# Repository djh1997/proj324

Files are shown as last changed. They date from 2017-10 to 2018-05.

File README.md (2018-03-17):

# **Final Year Project**

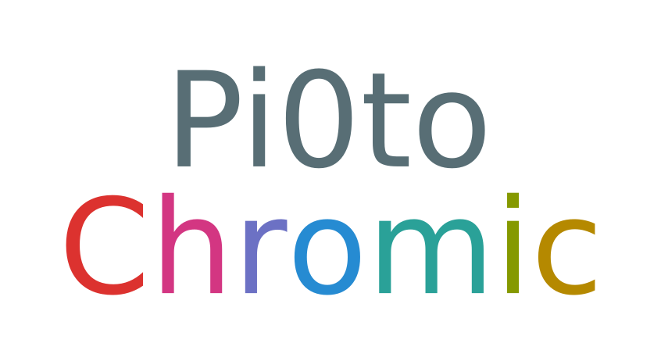
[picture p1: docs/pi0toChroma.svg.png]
pi0toChroma logo


# Stage Criteria

This is the criteria I would like to meet, to feel as though I have created a successful project.

| Stage | Name | Description |
| ----- | --- | --- |
| 1 | Smart shades | Make a set of smart sun classes |
| 2 | Auto smart shades | Add LDR to control the opacity |
| 3 | Auto smart point shades | Add camera to make dark point over bright points |
| 4 | Controllable smart shades | Add options to swap between modes |
| 5 | Driving/safety improvements | Auto react headlights etc. |

## Inspiration

[indie-go-go](https://www.indiegogo.com/projects/ctrl-one-the-smartest-lcd-tint-changing-glasses-smart#/)

[ctrl-eyewear](http://www.ctrl-eyewear.com/)

[pc case](https://www.youtube.com/watch?v=E5d7ynJXiZc)

## Plan

The product's above, along with Paul's lectures last year inspired my idea.

The plan is to use two LCD's with the backlight removed, to create dimmable panels in front of the users eyes. Then eventually I will add a camera to make point control which will block bright spots such as projectors and the sun, and dim them to reduce squinting.

# Final mock-up

final mock-up design image

So, once I have removed the backlight from the LCD's I can mount them in a frame. I can then begin to control the contrast/pixel density to make them dim. I will then add a LDR to automate the brightness selection, this will remove the manual adjust however I will leave the buttons to set the levels. Next I will add a camera to the system so that the system can also detect bright points hence make a matching point darker on the lens. I will then use the buttons to make it so that you can swap between the modes. The final additional feature I would like to add is some intelligence on the camera side to ignore certain circumstances such as car tail/headlights

# Report

I got the LCD hooked up and displayed some random spots of different opacity on the screen

[random point video](/docs/log/IMG_1188.TRIM.MOV)

I tried to install opencv to do the image processing built the install failed and after I spoke to my supervisor he confirmed my suspicion that opencv was too over powered for my project

so I did some more research around low power blob detection in python and found Skimage which has a function for Determinant of Hessian(doh) blob detection which should be quick enough the only issue I then had was getting the image from the camera into the right format since the doh blob need a numpy array as luck would have it skimage has a built in converter

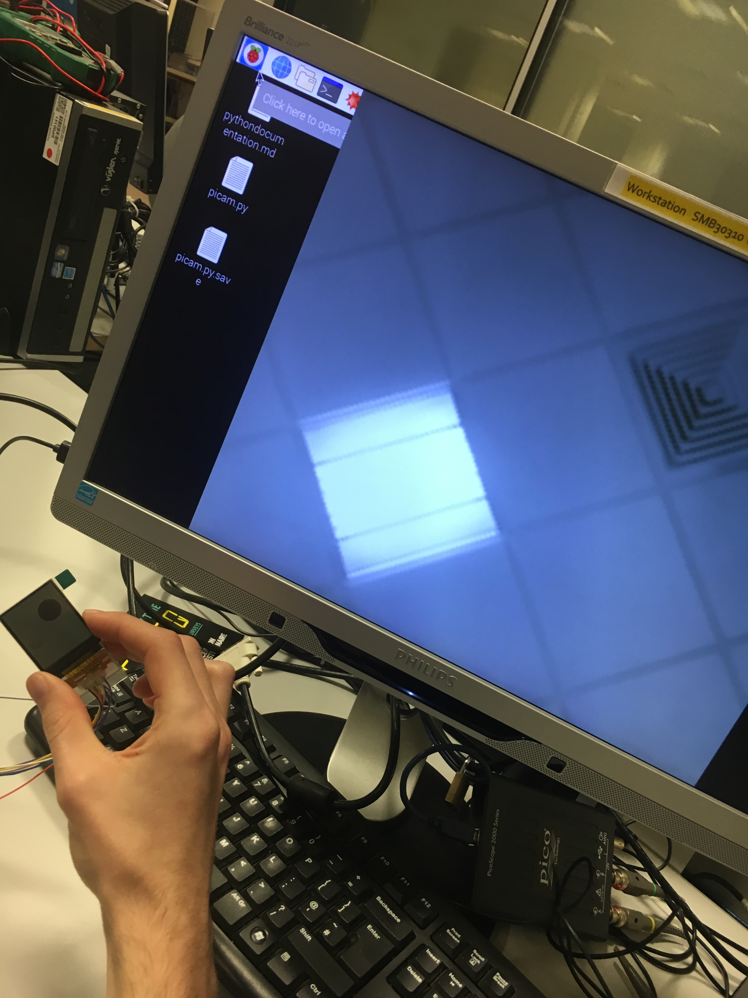
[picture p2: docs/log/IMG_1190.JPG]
final mock-up design image
I then connected the camera and started blob detection and got that working 

then I started to convert the shades.py (the file that controls the lcd and camera) and telegrambot.py (the script that enables remote control via a chat client bot) this involved more work than I had initially expected since passing variable around wasn't as easy as I had hoped

I decided to use telegram to add remote control so that you could adjust the colour of the tint [remote control](https://t.me/smartsheadsfypbot)

| command | param | Description |
| --- | --- | --- |
| help | na | show the help menu |
| pickcolour  | pick from list of tints | preset tints/colours |
| pickmode | pick manual,tint,points or full auto | change current mode |
| tellmeajoke | na | tells a joke |
| tint | percentage | sets the tint of the lenses |
| up | na | see if the bot is up |
| temp | na | see the CPU temperature |
| start | na | starts shades |
| stop | na | stop shades |
| exit | na | exit shades |
| reboot | na | reboot shades |
| halt | na | shutdown shades |
| uprecords | na | see up time |
| debug | na | toggles debug |
| colourset | fore/back@0/255,0/255,0/255 | sets the colour of the lenses |
| allowAllIds | na | toggles if user id is needed  |

After I had all of the system working I bought a 5 button capacitive touch sensor and started adding that into the code so that I would be able to control the glasses with out having to have it connected to the internet

| button | pressed | held |
| --- | --- | --- |
| 1 | scroll tints | reset tint to clear |
| 2 | scroll modes | reset to manual |
| 3 | debug | turn off |
| 4 | stop | start |
| 5 | na | exit |

# capacitive touch control

[mode change](/docs/log/capmode.MOV)
[tint change](/docs/log/tint.MOV)
[debug toggle](/docs/log/debug.MOV)

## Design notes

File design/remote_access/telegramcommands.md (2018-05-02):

help - show the help menu
pickcolour - pick from list of tints
pickmode- manual,tint,points or full auto
tint - percentage
image - shows you the current image
up - see if the bot is up
temp - see the CPU temperature
start - starts shades
stop - stop shades
exit - exit shades
reboot - reboot shades
halt - shutdown shades
uprecords - see up time
debug - toggle debug
buttons - toggle buttons
colourset - fore/back@0/255,0/255,0/255
allowallids - toggles if admin id is required

| command | param | Description |
| --- | --- | --- |
| help | na | show the help menu |
| pickcolour  | pick from list of tints | preset tints/colours |
| pickmode | pick manual,tint,points or full auto | change current mode |
| tint | percentage | sets the tint of the lenses |
| image | na | shows you the current image |
| up | na | see if the bot is up |
| temp | na | see the CPU temperature |
| start | na | starts shades |
| stop | na | stop shades |
| exit | na | exit shades |
| reboot | na | reboot shades |
| halt | na | shutdown shades |
| uprecords | na | see up time |
| debug | na | toggles debug |
| colourset | fore/back@0/255,0/255,0/255 | sets the colour of the lenses |
| allowAllids | na | toggles if admin id is needed |

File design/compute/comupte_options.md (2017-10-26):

<http://www.st.com/content/st_com/en/products/microcontrollers/stm32-32-bit-arm-cortex-mcus/stm32-high-performance-mcus/stm32f4-series/stm32f429-439/stm32f429zi.html>

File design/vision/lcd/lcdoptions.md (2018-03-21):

<http://uk.rs-online.com/web/p/oled-displays/0554314/>

<http://uk.farnell.com/midas/mct0144c6w128128pml/display-tft-lcd-1-44-transmissive/dp/2606862>

# lcd

[pickedlcd](https://www.adafruit.com/product/618)

## pinout

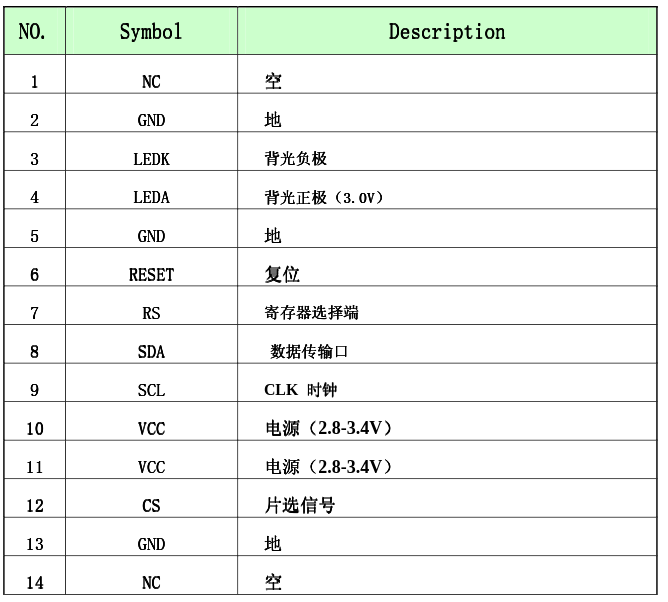
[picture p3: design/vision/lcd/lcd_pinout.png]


| lcd pin number | name  | used | colour | pi pin |
| --- | ----- | ---- | --- | --- |
| 1 | NC | no | na | |
| 2 | gnd | ? | purple | 20 |
| 3 | ledk  | no | na | |
| 4 | leda  | no | na | |
| 5 | gnd | ? | pink | 20 |
| 6 | reset | yes  | blue | 22 |
| 7 | rs/dc | yes  | grey | 18 |
| 8 | sda | yes  | yellow | 19 |
| 9 | scl | yes  | green  | 23 |
| 10 | vcc | yes  | orange | 17 |
| 11 | vcc | yes  | na | |
| 12 | cs | yes  | white  | 24 |
| 13 | gnd | ? | black  | 20 |
| 14 | NC | no | na | |

# lcd maths

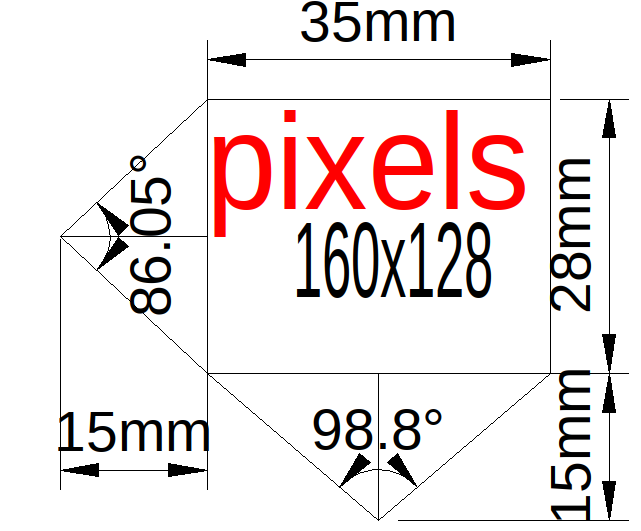
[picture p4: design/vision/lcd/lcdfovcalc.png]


$$ { \frac {128} {86.05}} = 1.48 \text{ vertical degrees per pixel}$$

$$ { \frac {160} {98.8}} = 1.62 \text{ vertical degrees per pixel}$$

# pi points

| function | colour | pi pins chip side | pi pin | colour  | function |
| --- | --- | --- | --- | --- | --- |
| vcc | orange | 17 | 18 | grey | rs |
| sda | yellow | 19 | 20 | black/p | gnd |
| | nc | 21 | 22 | blue | reset |
| scl | green  | 23 | 24 | white | cs |

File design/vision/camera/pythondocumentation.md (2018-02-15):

[docs](https://picamera.readthedocs.io/en/release-1.13/index.html)

- 5MP sensor, 2592x1944 pixels (same as version 1 official Pi camera)
- 1080p video at 30 FPS (or 60 FPS at 720p, 90 FPS at 480p)
- f2.9 lens, 3.60 mm focal length
- 53.50 degrees horizontal, 41.41 degrees vertical field of view (standard and no IR filter versions)
- Approx. dimensions of circuit and camera: 60 x 11.4 x 5.1mm

```bash
sudo apt-get update
sudo apt-get install python3-picamera
```

```python
import picamera
from time import sleep

camera = picamera.PiCamera()

camera.capture('image1.jpg')
sleep(5)
camera.capture('image2.jpg')
```

opencv failed to install and Phil said i would be better off using a simpler program to reduce compute time so am looking at numpy and [skimage](https://github.com/scikit-image/scikit-image)

[b&w image](https://picamera.readthedocs.io/en/release-1.13/api_camera.html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)

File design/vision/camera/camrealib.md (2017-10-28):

<https://os.mbed.com/users/edodm85/notebook/ov7670-camera-module/>

<https://os.mbed.com/users/ms523/notebook/ov7670-camera/>

<http://www.instructables.com/id/OV7670-Without-FIFO-Very-Simple-Framecapture-With-/>

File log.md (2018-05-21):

# Tasks

-   [x] get camera working
-   [x] get pi connected over WiFi
-   [x] get LCD connected
-   [x] get raw data from camera for processing
-   [x] get raw brightness from LDR or camera
-   [x] adjust opacity of LCD
-   [x] add image inversion
-   [x] add options to swap between modes
-   [x] laser cut glasses frame

# Extras

-   [x] add some form of app to control settings
-   [x] add options for dimming colour e.g. turn tint red instead of grey tint

# 16/11/2017

connect raspberry pi zero to home WiFi and successfully take photos

# 17/11/2017

successfully connect pi0w to eduroam and take photos

# 18/11/2017

start designing the frame

# 19/11/2017

start work with LCD

-   find c++ library from adafruit [ST7735-c+++](https://github.com/adafruit/Adafruit-ST7735-Library)
-   find python library [ST7735-micro](https://github.com/hosaka/micropython-st7735), [ST7735-af c++ forked to py](https://github.com/cskau/Python_ST7735)

looking thought the code the ST7735-micro seems cleaner and looks like I will be able to modify it easier since it is broken into more small functions although the other python has image support so I will try both and access

# 02/02/2018

start working on project again after exams/coursework and Christmas break but WiFi has stopped working possibly because of certification update but even reslashing the board and rerunning the cat installer didn't work will try to connect when I get home to check the WiFi chip is still working talked to Jake and said he should be able to put it on Plymouth humanoids

# 05/02/2018

work on time management and issue tracking

# 06/02/2018

today I finally got the pi0w connected to the uni WiFi and also got the vnc working so that I could work on the pi in uni without brining in a separate screen for the pi once I had done that I started work on the field of view calculations and realised that with out a fisheye camera adapter the lcd has a bigger fov so only the centre will be usable for point adjustment I also calculated the pixels per angle and realise that the only issue with using a fish eye adapter would cause distortion

then followed this [guide](https://www.pyimagesearch.com/2015/12/14/installing-opencv-on-your-raspberry-pi-zero/) to install open cv reach

```bash
pip install numpy
```

before running out of time before space x falcon heavy launch

# 07/02/2018

spacex falcon heavy launch was a success

-   switch to opencv 3.4.0 and finish up install
-   add all dependences to repo

# 08/02/2018

install locked at 84%

# 09/02/2018

get lcd and pi0w header soldered and get pin mappings for each

# 13/02/2018

looking through the code for the lcd drivers again from (19/11/2017) I think the forked adafruit might be better

found skimage and think it will work well with camera

also make new simpler frame prototype ready for laser cutting

# 14/2/2018

had meeting with Phil and he seems happy with progress and direction I'm taking so all good there

# 15/02/2018

got lcd working and even got the lcd to output circles based on x,y,radius,opacity

got blob detection working 'live'

# 16/02/2018

got both lcds working and fine tune timings to work out where the issues are and fine tune the blob detection

# 17/02/2018

tidied files up and got telegram control integrated into shades with control over weather point detection is on or off and the colour / tint level

# 20/02/2018

finalized remote control(4 modes, more colours and toggle-able debug ) and begin optimizing code to try to improve fps f

# 27/02/2018

investigate [capacitve](https://www.rapidonline.com/adafruit-1362-standalone-5-pad-capacitive-touch-sensor-breakout-73-5337) control of system and mount the lenses into the frame and add price list

# 03/03/2018

begin investigating conversion to c/c++ command

```bash
raspistill -o cam.jpg -cfx 128:128 -ifx negative -w 160 -h 128 -rot 270 --thumb none -l
```

```bash
raspistill -t 1000 -tl 0 -o - > img.jpg -cfx 128:128 -ifx negative -w 160 -h 128 -rot 270 --thumb none
```

find [raspicam](http://www.uco.es/investiga/grupos/ava/node/40) cpp api for the camera possible [st7735R](https://github.com/vinodstanur/raspberry-pi-frame-buffer-mapping-to-160x128-ST7735R-LCD) library although might be screen output

[blob](https://github.com/keenerd/quickblob)

achieve 30 fps image stream although the new blob detection might be able to deal with video stream

# 08/03/2018

receive parts and measure current draw at .2/.3 A and start coding for capacitive buttons

# 12/03/2018

finish initial coding for capacitive buttons

# 13/03/2018

fully implement hold for extra functionality

# 14/03/2018

tidy button code and start thinking about mounting

# 16/03/2018

record progress and prep for progress demonstration

# 9/04/2018

implement addwifi so I can add wifi AP's easier using Telegram

# 12/04/2018

tidy debugging prints and improve access error text

# 17/04/2018

redesign the fame for capacitive board and tidy deinitialization of camera

# 20/04/2018

add print to debug toggle, add commenting, add link to access error reply, start making install script to install dependencies

# 22/04/2018

add time to boot and reboot reply to calculate reboot time

# 23/04/2018

tidy code and make pep257 compliant, only update LCD on value change in manual mode

# 24/04/2018

work on report and get new arms cut,fix error #29 ,and add exit functionality so reopen program

# 26/04/2018

do paper work and move telegram API keys to separate file

# 30/04/2018

tidy code by moving jokes, making buttons more dynamic and work on report

# 01/05/2018

work on report, poster and add try except to telegrambot

# 02/05/2018

get toggle-able buttons working and add more diagrams to the poster

# 08/05/2018

add vision explanations and get mum to read thought report

# 09/05/2018

improve wiring and work on poster and report

# 10/05/2018

add button diagram to poster and add references to Appendix, gantt and budget to report also I improved the inspiration section

# 11/05/2018

finalize poster add compute, LCD and camera choice

# 12/05/2018

add negative image mode and work on report

# 13/05/2018

embed images add existing market and relevant references

# 14/05/2018

add toc and glossary

# 16/05/2018

get report checked at writing cafe

# 18/05/2018

add more references and add abstract, acknowledgements

# 19/05/2018

improve general formatting ,add licence

# 20/05/2018

work on report add flowchart and correct gantt

# 21/05/2018

add telegram inline keyboard screen shot and open day photo

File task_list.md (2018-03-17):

-   [x] find LCD's
-   [x] remove backlight
-   [x] get pi connected to WiFi
-   [x] get camera working
-   [x] export DISPLAY=:0.0
-   [x] telegram intergration [inline keyboard](https://github.com/python-telegram-bot/python-telegram-bot/blob/master/examples/inlinekeyboard.py)
-   [ ] frame
-   [ ] task

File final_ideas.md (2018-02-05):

# Stage Criteria

This is the criteria I would like to meet, to feel as though I have created a successful project.

| Stage | Name | Description |
| ----- | --- | --- |
| 1 | Smart shades | Make a set of smart sun classes |
| 2 | Auto smart shades | Add LDR to control the opacity |
| 3 | Auto smart point shades | Add camera to make dark point over bright points |
| 4 | Controllable smart shades | Add options to swap between modes |
| 5 | Driving/safety improvements | Auto react headlights etc. |

## Inspiration

[indie-go-go](https://www.indiegogo.com/projects/ctrl-one-the-smartest-lcd-tint-changing-glasses-smart#/)

[ctrl-eyewear](http://www.ctrl-eyewear.com/)

[pc case](https://www.youtube.com/watch?v=E5d7ynJXiZc)

## Plan

The product's above, along with Paul's lectures last year inspired my idea.

The plan is to use two LCD's with the backlight removed, to create dimmable panels in front of the users eyes. Then eventually I will add a camera to make point control which will block bright spots such as projectors and the sun, and dim them to reduce squinting.

# Initial mock-up of design initial mock-up image

# Final mock-up final mock-up design image

So, once I have removed the backlight from the LCD's I can mount them in a frame. I can then begin to control the contrast/pixel density to make them dim. I will then add a LDR to automate the brightness selection, this will remove the manual adjust however I will leave the buttons to set the levels. Next I will add a camera to the system so that the system can also detect bright points hence make a matching point darker on the lens. I will then use the buttons to make it so that you can swap between the modes. The final additional feature I would like to add is some intelligence on the camera side to ignore certain circumstances such as car tail/headlights

# VHDL/FPGA(de o nano) vs. arm(stm32 vs. RPI)

I am currently undecided on the compute platform.

I'm leaning towards the arm side since the camera will likely be 30-60 fps and I believe that the arm will be quick enough. Also I think it will have better support for interfacing the camera and LCD also the STM boards have analogue io for the LDR and contrast for the LCD

After talking to my supervisor and lab tech they both recommended the raspberry pi as the platform. this recommendation is because of the price point of the zero w and the zero cam being so low and the large product support for the increased range of screens possible the only issue with this will be the fact the pi doesn't have analogue io so the dimming of the LCD will be harder but this should be easily worked around.

| component | quantity | price(£) | component type | chosen |
| --- | --- | --- | --- | --- |
| pi zero w | 1 | 9.60 | compute | yes |
| pi 3 | 1 | 35 | compute | no |
| stm32 | 1 | 18.11 | compute | no |
| de0nano | 1 | 67.16 to 84.46  | compute | no |
| MCT0144C6W128128PML | 2 | 7.57 | lens | no |
| DD-12864YO-3A | 2 | 16.12 | lens | no |
| AF 1.8" TFT ST7735R driver | 2 | 10 | lens | yes |
| pi zero camera | 1 | 15 | camera | yes |
| pi camera | 1 | 24 | camera | no |
| ov7670 | 1 | 5 to 10 | camera | no |
| ov7720 | 1 | .50 from ps eye | camera | no |
| DAC 0800 | 1 | 1.15. | DAC for LCD | yes |
| ZN439 | 1 | 2.50 | ADC for LDR | yes |

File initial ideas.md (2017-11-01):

# stage criteria

These are the criteria I would like to meet to feel as thought I have ached a successful project.

stage | name                        | description
----- | --------------------------- | ----------------------------------------------
1     | smart shades                | make a set of smart sun classes
2     | auto smart shades           | add LDR to control the opacity
3     | auto smart point shades     | add camera to make dark point over dark points
4     | controllable smart shades   | add options to swap between modes
5     | driving/safety improvements | auto react headlights ect.

## Inspiration

[indiegogo](https://www.indiegogo.com/projects/ctrl-one-the-smartest-lcd-tint-changing-glasses-smart#/)

[ctrl-eyewear](http://www.ctrl-eyewear.com/)

[pc case](https://www.youtube.com/watch?v=E5d7ynJXiZc)

## plan

this product along with Paul's lectures last year inspired the idea.

The plan is to use two LCD's with the backlight removed to create dimmable panels in front of the users eyes. Then eventually add a camera to make point control to block bright spots like projectors and the sun and dim them to reduce squinting.

# initial mock-up of design inital mock-up image

# hopeful final mock-up final mock-up design image

So once I have removed the backlight from the LCD's I can mount them in a frame I can then begin to control the contrast/pixel density to make them dim. I will then add a LDR to automate the brightness selection this will remove the manual adjust but I will Leave the buttons to set the levels. next I will add a camera to the system so that it can also detect bright points and make a matching point darker on the lens. I will then use the buttons to make it so you can swap between the modes. The final feature addition I would like to add is some intelligence on the camera side to ignore certain circumstances like car tail/headlights

# VHDL/FPGA(de o nano) vs. arm(stm32 vs. rpi)

I am currently undecided on the compute platform.

I'm leaning towards the arm side since the camera will likely be 30-120 fps and I believe that the arm will be quick enough. Also I think it will have better support for interfacing the camera and LCD also the STM boards have analogue i-o for the LDR and contrast for the LCD

After talking to my supervisor and lab tech they both recommended the raspberry pi as the platform. this recommendation is because of the price point of the zero w and the zero cam being so low and the large product support for the increased range of screens possible

component           | quantity | price(£)        | component type
------------------- | -------- | --------------- | --------------
pi zero             | 1        | 9.60            | compute
pi 3                | 1        | 35              | compute
stm32               | 1        | 18.11           | compute
de0nano             | 1        | 67.16 to 84.46  | compute
MCT0144C6W128128PML | 2        | 7.57            | lens
DD-12864YO-3A       | 2        | 16.12           | lens
pi zero camera      | 1        | 15              | camera
pi camera           | 1        | 24              | camera
ov7670              | 1        | 5 to 10         | camera
ov7720              | 1        | .50 from ps eye | camera

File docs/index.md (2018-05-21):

---
html:
  embed_local_images: true
---
# **Final Year Project**

pi0toChroma logo

By David Joseph Hawkins

Student no:10526354

School of Computing, Electronics and Engineering.

A report covering the theory, design, build and testing of a pair of dynamic sunglasses. Submitted to the University of Plymouth in partial fulfilment for the degree of BEng(Hons) Electrical and Electronic Engineering.

## Acknowledgements

A special thanks goes to my family, technical support staff, The Writing Cafe,  Philip Culverhouse and Nicholas Outram.

A thanks also goes to the makers of GitHub, GitGuardian, Telegram, Draw.io, Atom, GanttProject, Scikit-image, Etcher.io and Inkscape for their great services/software.

<!-- TOC depthFrom:1 depthTo:6 withLinks:1 updateOnSave:1 orderedList:0 -->

- [**Final Year Project**](#final-year-project)
	- [Acknowledgements](#acknowledgements)
	- [Glossary](#glossary)
- [Stage Criteria](#stage-criteria)
	- [Inspiration](#inspiration)
	- [Plan](#plan)
		- [Potential issues](#potential-issues)
		- [Timeline](#timeline)
- [Design Mock-up](#design-mock-up)
- [Report](#report)
	- [Compute](#compute)
		- [VHDL/FPGA(de0nano) vs. arm(STM32 vs. RPI)](#vhdlfpgade0nano-vs-armstm32-vs-rpi)
	- [Camera](#camera)
	- [LCD](#lcd)
		- [Theory](#theory)
		- [Wiring](#wiring)
		- [Testing](#testing)
	- [FoV](#fov)
		- [LCD](#lcd)
		- [Camera](#camera)
	- [Frame](#frame)
	- [Blob Detection](#blob-detection)
	- [Telegram](#telegram)
		- [Commands](#commands)
	- [Capacitive Touch Sensor](#capacitive-touch-sensor)
		- [Wiring](#wiring)
		- [Buttons](#buttons)
		- [Capacitive Touch Control](#capacitive-touch-control)
- [Conclusion](#conclusion)
	- [Criteria Met](#criteria-met)
	- [Budget](#budget)
	- [Time management](#time-management)
	- [Existing market](#existing-market)
	- [Technology readiness level](#technology-readiness-level)
- [Future Development](#future-development)
- [Appendix](#appendix)
	- [Coding languages](#coding-languages)
	- [Code](#code)
		- [telegrambot.py](#telegrambotpy)
		- [shades.py](#shadespy)

<!-- /TOC -->

## Glossary

| Abbreviation | Meaning |
| --- | --- |
| SPI | Serial peripheral interface |
| LDR | Light dependant resistor |
| LCD | Liquid crystal display |
| FPGA | Field programmable gate array |
| VHDL | Very high speed integrated circuit hardware description language |
| IO | Input output |
| GPIO | General purpose input output |
| FoV | Field of view |
| TRL | Technology readiness level |

# Stage Criteria

This is the criteria that the project aims to meet, to feel as though the project had succeeded.

| Stage | Name | Description |
| ----- | --- | --- |
| 1 | Smart shades | Make a set of smart sunglasses |
| 2 | Auto smart shades | Add LDR to control the opacity |
| 3 | Auto smart point shades | Add camera to make darks points over bright points |
| 4 | Controllable smart shades | Add options to swap between modes |
| 5 | Driving/safety improvements | Auto react to headlights etc. |

## Inspiration

The project was inspired by Linus tech tips video[^1] about the IBuyPower Snowblind case[^2]. It was then that the idea for reactive sunglasses using LCD was formed. While researching to see if this had already been done, ctrl-one glasses were discovered and have similarly been created[^3].

The ctrl-one product starts down the same path as this project would like to take but are binary whereas this project aims for different levels of tinting and active shading. To achieve this it will be required to use an LCD panel with pixels instead of a single panel. Also, one of the ctrl-one products main unique selling points is the sub 0.1 second light to dark time[^4]; which will ideally be surpassed. The other advantage this product will have over ctrl-one will be cost since, ctrl-one costs $299, while this product aims to be priced under £100[^5] (set by the budget limit).

## Plan

The products above, along with Paul Davey's lectures last year inspired the idea.

The plan is to use two LCD's with the backlight removed, to create dimmable panels in front of the users eyes. Then eventually a camera will be added to create multiple point controls which will block bright spots such as projectors and sunlight thus, dimming them to reduce squinting.

### Potential issues

-   IO speed, depending on the solutions used in the project, could end up being an issue with bottle necks affecting frame rate.
-   Frame rate for the active points would need to be fairly high to stop nauseating effects.
-   Camera distortion, a camera with little to no distortion would ideally be used since this would make image processing easier.
-   Field of view, having a similar FoV would be useful since a camera with smaller FoV would end up wasting the edge of the LCD.
-   Aspect ratio, mismatch of aspect ratios without the use of accelerometers for predictive tracking could cause issues.

### Timeline

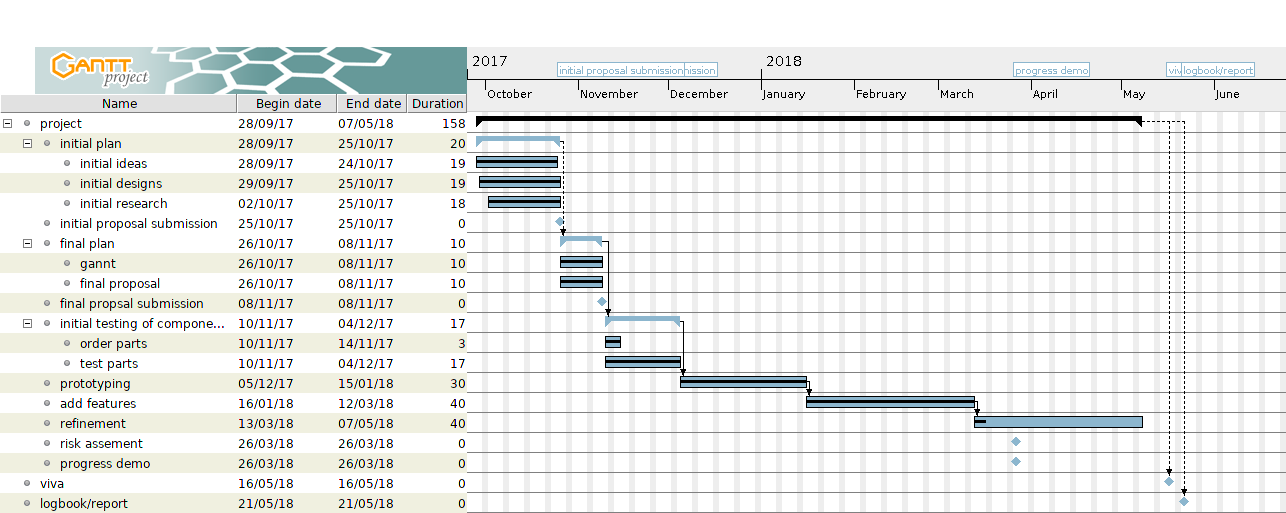
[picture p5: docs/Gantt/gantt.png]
gantt


A gantt chart was made using GanttProject[^6]

# Design Mock-up

final mock-up design image

So, once the backlight was removed from the LCD's they can mount them into the frame. Then the LCDs can begin to be controlled by adjusting the contrast/pixel density to make them dim using a button.

After which an LDR can be added to automate the brightness selection, the manual adjust however will be left in, at which point the button can still be used to switch between the different sensitivity levels.

Next a camera will be added to the system so that the system can detect bright points, hence make a matching point darker on the lens.

At which point the buttons can be used so that you can switch between different modes. The final additional feature that will be added is some intelligence on the camera side to ignore certain circumstances such as car tail/headlights.

# Report

## Compute

### VHDL/FPGA(de0nano) vs. arm(STM32 vs. RPI)

For the compute unit the main options available are arm or FPGA. Theoretically the FPGA will have higher parallel though put for the camera to LCD interface. Although arm will have image processing libraries which will expedite the prototyping process. The other main advantage with arm is the reduced cost.

| Component | Quantity | Price(£) | Component type | Chosen |
| --- | --- | --- | --- | --- |
| pi 0 w | 1 | 9.60 | compute | yes |
| pi 3 | 1 | 35 | compute | no |
| STM32 | 1 | 18.11 | compute | no |
| de0nano | 1 | 67.16 to 84.46 | compute | no |

I'm leaning towards the arm side since the camera will likely be 30-60 fps. I believe that an arm  chip will be quick enough. Also it will have better support for interfacing the camera and LCD; the STM boards have analogue IO for the LDR and contrast for the LCD.

After talking to supervisors and lab technicians they both recommended the raspberry pi as the platform. This recommendation is because of the price point of the zero w and the zero cam being so low as well as, the large product support for the increased range of screens possible. The only issue with this will be the fact the pi doesn't have analogue IO so the dimming of the LCD will be harder but this should be easily worked around.

The other advantage of the raspberry pi 0 is it has a file system and wifi so code can be remotely deployed once it is connected. This will make the development cycle much quicker.

## Camera

| Component | Quantity | Price(£) | Component type | Chosen |
| --- | --- | --- | --- | --- |
| pi 0 camera | 1 | 15 | camera | yes |
| pi camera | 1 | 24 | camera | no |
| ov7670 | 1 | 5 to 10 | camera | no |
| ov7720 | 1 | .50 from ps eye | camera | no |

The options for the camera were good but the pi 0 camera was picked, since it had the best compromise between cost and libraries[^7].

## LCD

LCD's will be used to reduce the amount of light reaching the users eyes. The way an LCD works is like a stain glasses window with a frosted glasses window and bright light behind. But with an LCD you can change the colour and brightness of the stain. This is the effect that will be used to dynamically adjust the amount of light reaching the users eyes.

| Component | Quantity | Price(£) | Component type | Chosen |
| --- | --- | --- | --- | --- |
| MCT0144C6W128128PML | 2 | 7.57 | lens | no |
| DD-12864YO-3A | 2 | 16.12 | lens | no |
| AF 1.8" TFT ST7735R driver | 2 | 10 | lens | yes |

The adafruit 1.8" TFT ST7735R is going to be the best option since it's the best size for the lenses. Also there are drivers[^8] available for the raspberry pi.

### Theory

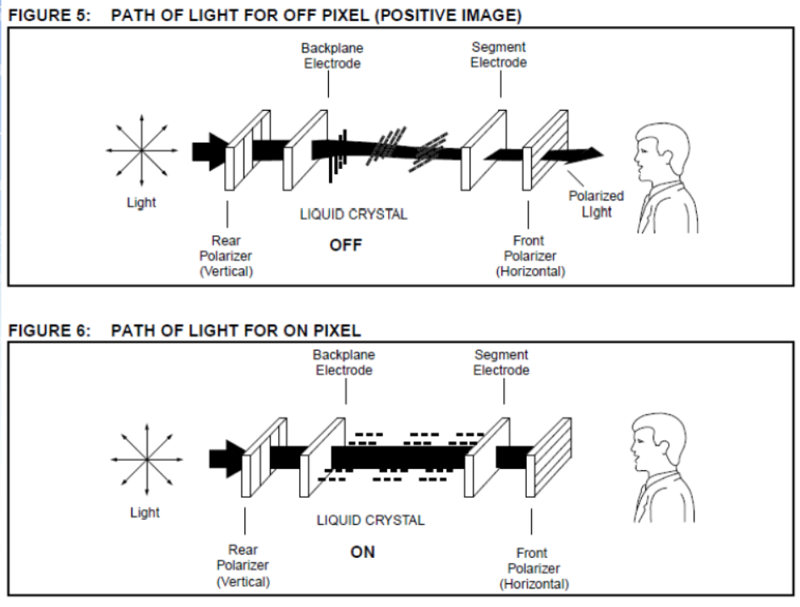
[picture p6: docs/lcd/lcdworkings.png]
LCD workings


In this diagram from Paul Davey's lecture[^9] on LCD's last year, you can see the inner workings of an individual pixel.

This works like so;

1.  Light enters the panel through the rear polariser. The light becomes vertically polarized.
2.  The polarized light then passes through the transparent backplane electrode.
3.  As the polarized light passes through the Liquid crystal fluid it gets twisted into the horizontal plane.
4.  The polarized light passes through the transparent pixel electrode.
5.  Because the light is polarized in the horizontal plane, it passes through the front horizontal polariser.

This is the effect that will be used to reduce the amount of light reaching the users eyes.

### Wiring

| Function | Colour | Pi pins chip side | Pi pin | Colour  | Function |
| --- | --- | --- | --- | --- | --- |
| vcc | Orange | 17 | 18 | Grey | rs |
| sda | Yellow | 19 | 20 | Black/P | gnd |
| N/A | nc | 21 | 22 | Blue | reset |
| scl | Green  | 23 | 24 | White | cs |

### Testing

I connected the LCD and displayed some random size and location spots of different opacity on the screen.

[random point video](https://git.djh1997.uk/log/IMG_1188.TRIM.MOV)

After this, the entire screen was set to one tint, then changed to a different tint. This meant you could see the update "wipe" across the screen.

This will cause issues since the SPI is already at the max speed.

It was also tried to consolidate/disconnect the grounds of the LCD but this caused issues so the wiring was returned to the original configuration.

## FoV



Field of view(FoV) is the area that you can see. It is normally measured in degrees. For simple mapping it is required that the FoV of the camera and LCD to be the same. Other issues include;

Aspect ratio


Distortion
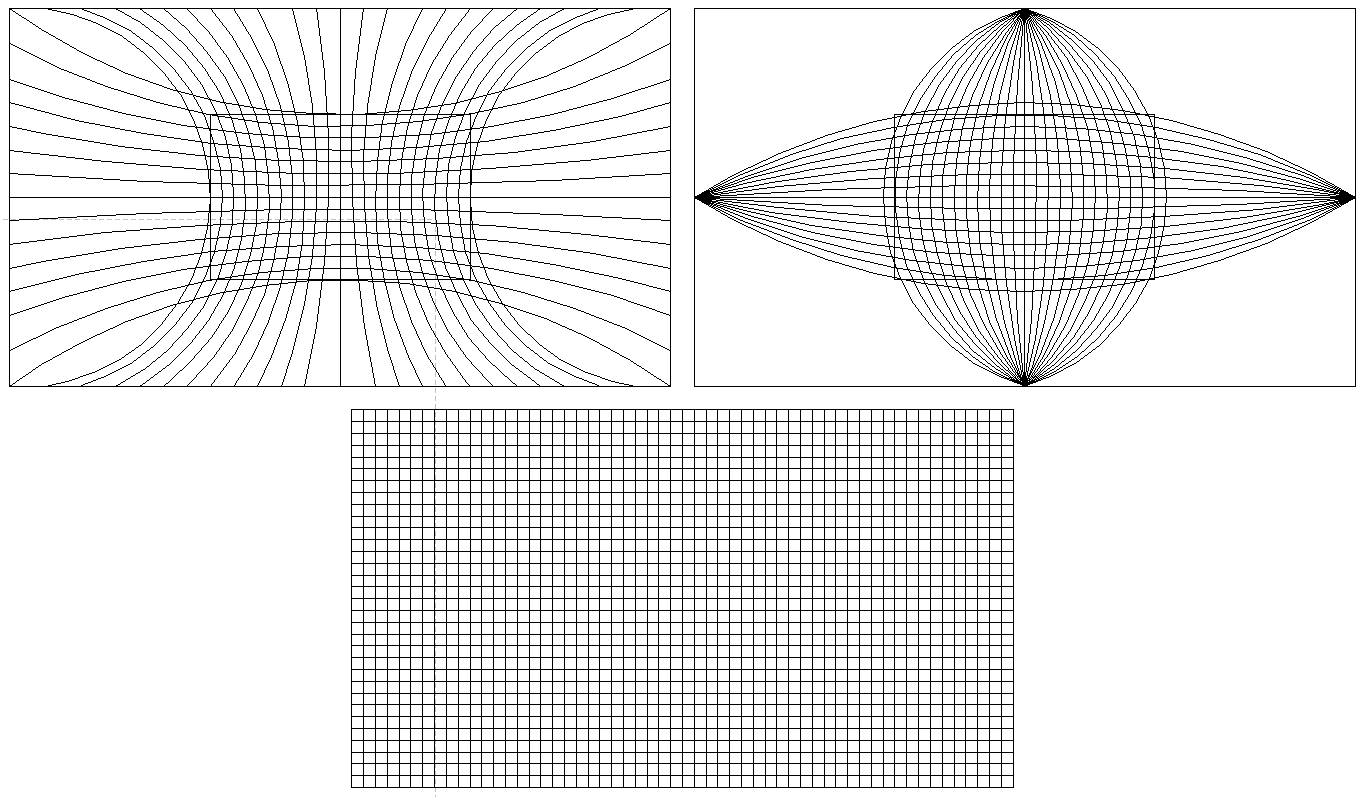
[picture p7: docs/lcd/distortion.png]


### LCD


160x128 pixels

98.8 degrees horizontal, 86.05 degrees vertical field of view

$$ { \frac {128} {86.05}} = 1.48 \text{ vertical pixels per degree}$$

$$ { \frac {160} {98.8}} = 1.62 \text{ horizontal pixels per degree}$$

### Camera

2592x1944 pixels

53.50 degrees horizontal, 41.41 degrees vertical field of view

$$ { \frac {1944} {41.41}} = 46.95 \text{ vertical pixels per degree}$$

$$ { \frac {160} {98.8}} = 48.45 \text{ vertical pixels per degree}$$

So, this will cause issues since the dot placed on the LCD will end up in the wrong place without scaling.

## Frame

The frame was cut by a laser cutter since this would be more cost and time effective. Also glasses frames tend to be fairly 2-dimensional. In the following image you can see the design iterations.

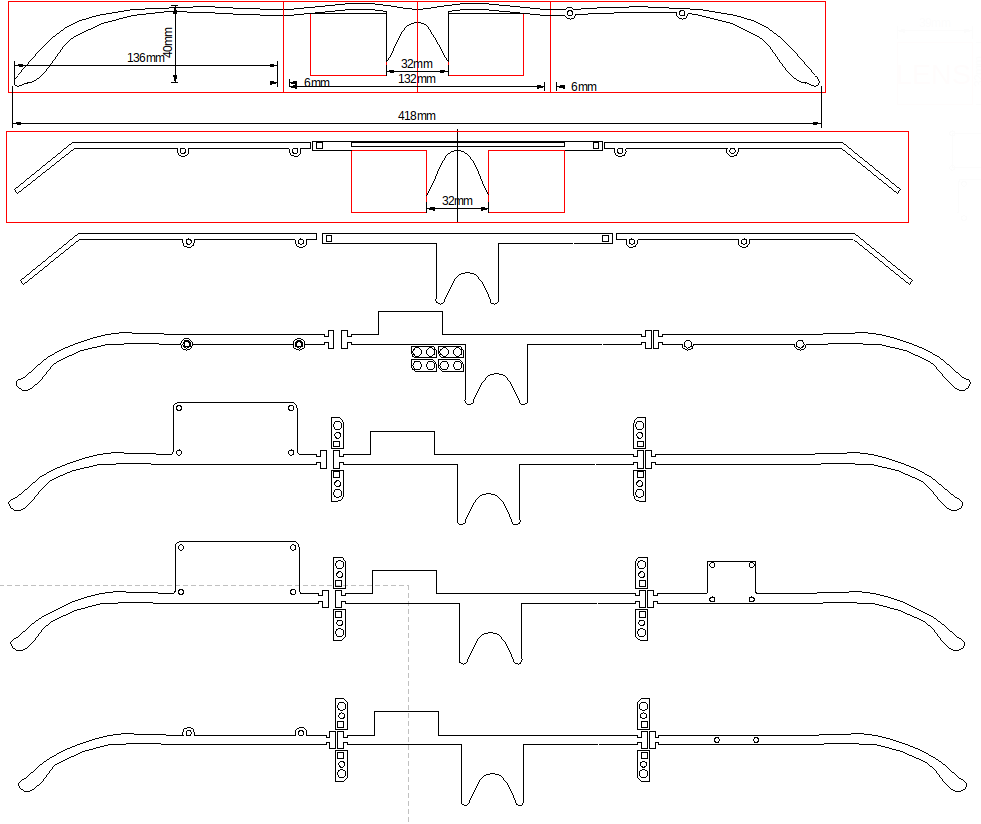
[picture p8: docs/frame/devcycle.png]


The initial idea was to heat the acrylic and bend at the red line, meaning that you wouldn't be able to fold them.

The next idea was another fixed design, but with a simpler shape. It was decided to go with this idea rather than the former so this was the first iteration that actually got cut. It was found that the lens was going to be too close to the eye and the ribbon cable from the lens was going to dig in to the brow of users nose. This was solved in the third iteration by making the increasing distance between the top of the frame and the top of the nose support. This forced the user to wear the glasses further down their nose.

After this, a hinging mechanism was designed and the curves re-added to make the glasses more comfortable. A mounting bracket for the camera was also added. This was the frame that was cut and used for most of the prototyping phase of the project.

For the next two designs the plan was to add a backing plate to the pi mount and also adding a mount for the capacitive touch sensor. This design was never cut since the pi 0 needs clearance for the solder of the pin headers. Also the backing might have added too much weight. The design of the hinge was furthered by squaring off one of the ends to make it more rigid, adding a hole to hold it together this also serves to adjust the resistance of the arms.

## Blob Detection

The initial idea for blob detection was to import the grey scale image as a matrix of values. Then to iterate over it, looking for a difference in values or checking against a threshold value. However, it was difficult to get the image in as a matrix and even using an example matrix because the code wasn't running very quickly or reliably.

Installation of opencv for image processing was attempted but the install failed. After speaking to a supervisor he confirmed that opencv was too overpowered for my project.

More research was then done around low power blob detection in python. Skimage[^10] (a library for python) was then found which has a function for Determinant of Hessian(DoH) blob detection. This was lightweight, meaning it would be quick enough for image processing. The only remaining issue was getting the image from the camera into the right format. Skimage has a built in numpy array converter which was fortunate since the DoH blob detection needs a numpy array to function.

With this working an image from the camera passed to the program, which saved the image with a circle around the blob to test the accuracy of the system.

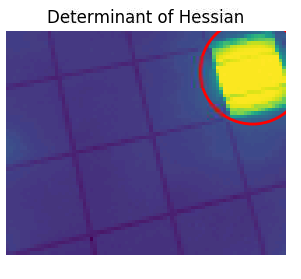
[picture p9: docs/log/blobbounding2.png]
blob circle


I then connected the LCD and got blob detection working with that.

blob LCD

Next the code was optimised, by reducing the resolution of the camera feed and adjusting the sensitivity of the blob detection. This improved the blob finding time from 25-30 seconds down to 0.03 seconds.

## Telegram

Then shades.py (the file that controls the LCD and camera) and telegrambot.py (the script that enables remote control via a chat client bot) were converted to work together. This involved more work than was initially anticipated, since passing variables around wasn't as easy as hoped.

It was decided that telegram[^11] would be used to add remote control, so that you could adjust the colour of the tint [remote control](https://t.me/smartsheadsfypbot).

After telegram was integrated, the security on an open chat bot was a big concern but after some looking through the documentation, admin only access was found.[^12] This was then implemented using a list of admin id's and a toggle for less important settings.

An inline keyboard was also added for picking between a set of options.

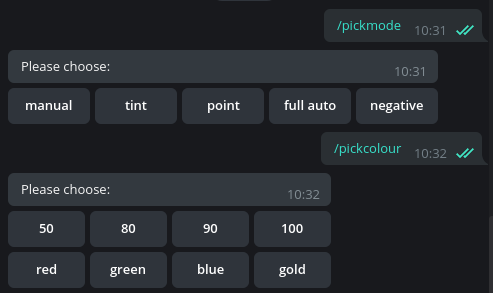
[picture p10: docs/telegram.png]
telegram


### Commands

| Command | Parameters | Description |
| --- | --- | --- |
| help | N/A | Show the help menu. |
| pickcolour  | Pick from list of tints | Preset tints/colours. |
| pickmode | Pick from list of modes | Change current mode. |
| tint | Percentage | Sets the tint of the lenses. |
| image | N/A | Shows you the current image. |
| up | N/A | See if the bot is up. |
| temp | N/A | See the CPU temperature. |
| start | N/A | Starts shades. |
| stop | N/A | Stop shades. |
| exit | Admin only | Exit shades. |
| reboot | Admin only | Reboot shades. |
| halt | Admin only | Shutdown shades. |
| uprecords | N/A | See up time. |
| debug | N/A | Toggles debug. |
| buttons | Admin only | Toggles buttons. |
| colourset | fore/back@0/255,0/255,0/255 | Sets the colour of the lenses. |
| allowallids | Admin only | Toggles if admin ID is needed. |

## Capacitive Touch Sensor

After the entire system was working a 5 button capacitive touch sensor was bought. The sensor was then added into the code, so that it would be able to control the glasses without the need for the glasses to be connected to the internet.

### Wiring

| Function | Colour | Pi pins chip side | Pi pin | Colour | Function |
| --- | --- | --- | --- | --- | --- |
| 3.3v | nc | 1 | 2 | nc | 5v |
| Button 1 | Orange | 3 | 4 | Red | 5v |
| Button 2 | Yellow | 5 | 6 | Black  | gnd |
| Button 3 | Green  | 7 | 8 | Blues  | Button 4 |
| gnd | nc | 9 | 10 | Purple | Button 5 |

### Buttons

| Button | Colour | Pressed | Held |
| --- | --- | --- | --- |
| 1 | Orange | Scroll tints | Reset tint to clear |
| 2 | Yellow | Scroll modes | Reset to manual |
| 3 | Green  | Debug | Turn off |
| 4 | Blue | Stop | Start |
| 5 | Purple | N/A | Exit |

For the final design only three buttons were used since the frame was beginning to get a bit cluttered with wires and boards.

buttonlocations

It was also decided that it would be best to keep all the buttons on one side of the frame, since the capacitive touch sensitivity was a bit to high and you couldn't change it on this board. This meant you're less likely to have accidental readings from touching the wire if the wires are kept short and tucked out of the way.

Later Alex Baron suggested wrapping the sensor wire in thin pieces of wire to shield the wire by grounding the insulation. This worked really well.

### Capacitive Touch Control

[Mode change](https://git.djh1997.uk/log/capmode.MOV)
[Tint change](https://git.djh1997.uk/log/tint.MOV)
[Debug toggle](https://git.djh1997.uk/log/debug.MOV)

# Conclusion

## Criteria Met

-   [x] Make a set of smart sunglasses.
-   [x] Add automatic of control the opacity.
-   [x] Add camera to make dark points over bright points.
-   [x] Add options to swap between modes.
-   [ ] Auto react to headlight/safety improvements.

All of the stage criteria were met except reaction to headlights. It was decided that this wasn't a good idea, since this could interfere with the drivers sight, so this mode will be left out. Other safety features added were resetting when you held any mode button. Except for a catastrophic error, the system is fail safe not deadly meaning it clears the LCD before exiting.

Finally an install script was made for the dependencies so that they would all be installed and configured correctly.

final flowchart

## Budget

| Name | Price | Quantity | Total |
| --- | ----- | --- | ----- |
| [pi0w](https://thepihut.com/collections/raspberry-pi/products/raspberry-pi-zero-w) | 9.60  | 1 | 9.60  |
| [lcd](https://thepihut.com/collections/lcds-displays/products/adafruit-1-8-spi-tft-display-160x128-18-bit-color-st7735r-driver) | 10 | 2 | 20 |
| [pi0 camera](https://thepihut.com/collections/raspberry-pi-camera/products/zerocam-camera-for-raspberry-pi-zero) | 15 | 1 | 15 |
| [pi0 pibow](http://cpc.farnell.com/pimoroni/pim258/pibow-zero-w-case/dp/SC14550?st=pibow%20cases) | 4.19  | 1 | 4.19  |
| [pi0 metal case](http://cpc.farnell.com/kksb/110221b/metal-case-for-raspberry-pi-zero/dp/SC14486) | 3.99  | 1 | 3.99  |
| [hdmi to dvi-d](http://cpc.farnell.com/pro-signal/psg04003/lead-hdmi-m-dvi-24-1-m-1m/dp/AV25309?st=hdmi%20to%20dvi) | 2.35  | 1 | 2.35  |
| [usb ammeter](https://www.rapidonline.com/voltcraft-pm-37-digital-usb-power-meter-64-2822) | 7.26  | 1 | 7.26  |
| [capacitive sensor](https://www.rapidonline.com/adafruit-1362-standalone-5-pad-capacitive-touch-sensor-breakout-73-5337) | 7.48  | 1 | 7.48  |
| veroboard | 3.60  | 1/4 | .90 |
| 64GB Class 10 MicroSDXC UHS-1 Memory Card & SD Adaptor | 24.95 | 1 | 24.95 |
| total | | | 95.72 |

## Time management

The time management for the project was fairly good except the fact Christmas holidays/January exams weren't accounted for. But there was enough slack incorporated in to the timeline that the project was back on track in just over a month.

## Existing market

| Component | Price |
| --- | ----- |
| pi 0 W | 9.60  |
| capacitive sensor | 0.74  |
| LCD | 20 |
| camera | 15 |
| total | 45.34 |

This is considerably less than the existing market, so even with adding the frame and battery it will be cheaper.

Although the current  refresh rate is lower at the moment, with a change of panel and main compute chip the system will be able to run considerably quicker.

## Technology readiness level

The project as of this point has met a technology readiness level of at least level 4, even pushing some level 5 criteria as defined by the European Commission[^13].

| Level  | Definition |
| --- | --- |
| TRL 1. | Basic principles observed. |
| TRL 2. | Technology concept formulated. |
| TRL 3. | Experimental proof of concept. |
| TRL 4. | Technology validated in lab. |
| TRL 5. | Technology validated in relevant environment (industrially relevant environment in the case of key enabling technologies). |
| TRL 6. | Technology demonstrated in relevant environment (industrially relevant environment in the case of key enabling technologies). |
| TRL 7. | System prototype demonstration in operational environment. |
| TRL 8. | System complete and qualified. |
| TRL 9. | Actual system proven in operational environment (competitive manufacturing in the case of key enabling technologies; or in space). |

The European Association of Research and Technology Organisations (EARTO) has a slightly more relevant scale of TRL[^14].

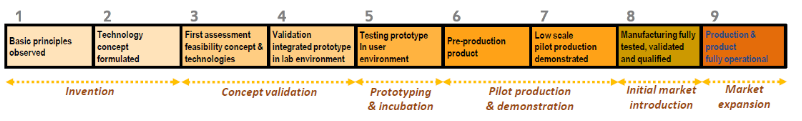
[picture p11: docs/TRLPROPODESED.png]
TRL


The project fits this scale better and is also a level 4, with aspects of level 5 according to this scale.

# Future Development

The current setup is mostly a proof of concept. For a full prototype/production model, a chip with high IO rates like a DSLR image processing chip, with a low quality and high frame rate camera with a bare LCD would be used to make the system run faster.

Because of the image processing chip it would be possible to increase the communication speed, since the IO is the limiting factor on the current setup.

The biggest IO limit at the moment is the LCD, this is because the only reasonably priced LCD's at this size that were available on the market use an SPI communication link. Also the LCD driver chip is fairly slow using this link.

The other main issue is the fact this system assumes your eyes are always directly behind the LCD. So, for a fully fledged system it would be required that some form of simple eye tracking should be added to compensate for this.

While talking to Martin Slade about the project, one individual mentioned research which could add dynamic prescription[^15]. This would be a good addition to the project as this would make the glasses truly dynamic in the sense of not needing to buy another pair of glasses in the future as, the tint and prescription can be adjusted for users.

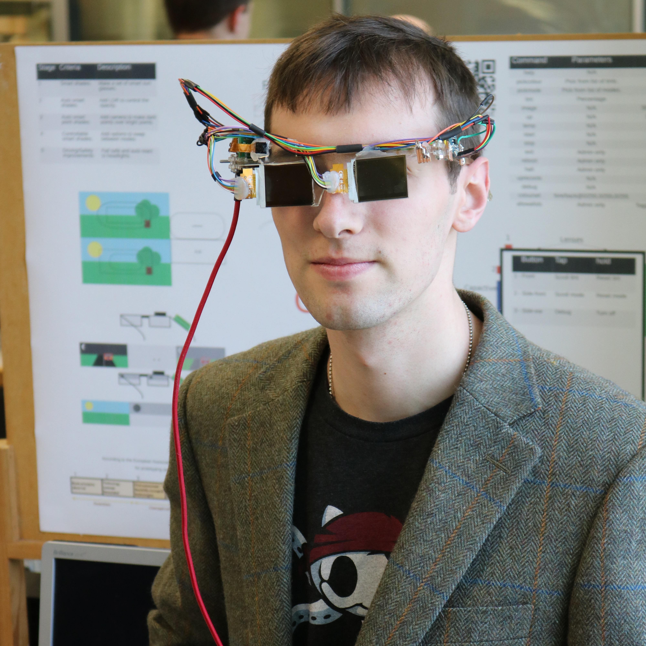
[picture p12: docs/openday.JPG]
open day


**<>** By David Joseph Hawkins using **Atom** and [**GitHub**](https://github.com/djh1997/proj324)

# Appendix

## Coding languages

code

## Code

### telegrambot.py

```python
"""Telegram control file."""
import os
import subprocess
from functools import wraps
from random import choice, randint
from time import strftime

from shades import (buttonstoggle, debugset, getiso, modeset, runningstateget,
                    runningstateset, sandd, scaleFactorset, tintBackset,
                    tintShadeset)
from telegram import InlineKeyboardButton, InlineKeyboardMarkup, ParseMode
from telegram.ext import (CallbackQueryHandler, CommandHandler, Filters,
                          MessageHandler, Updater)

"""program variables"""
test_box_api_key = []
test_box = 0
user = False
admins = []
allowAll = True
jokelist = []

"""retrive telegram keys"""
try:
    f = open('telegramkeys.txt', 'r')
    test_box_api_key.append(f.readline().split('\n')[0])
    admins.append(int(f.readline().split('\n')[0]))
    f.close()
except IOError:
    print 'telgram import fail'
    exit()

"""retrive jokes"""
try:
    f = open('jokes.txt', 'r')
    for line in f:
        jokelist.append(line)
    f.close()
except IOError:
    jokelist = ['joke import failed']
    print jokelist[0]

"""Create the EventHandler and  it your bot's token."""
updater = Updater(test_box_api_key[test_box])
jbq = updater.job_queue

def restricted1(func):
    """Add re-stricter for access."""
    @wraps(func)
    def wrapped(bot, update, *args, **kwargs):
        user_id = update.effective_user.id  # get user id
        if allowAll or user_id in admins:  # if in open mode or admin id
            return func(bot, update, *args, **kwargs)  # run function
        update.message.reply_text(
            "Access denied for {}.Ask [Jo](tg://user?id={}) for access.".
            format(user_id, admins[0]),
            parse_mode=ParseMode.MARKDOWN
        )  # else echo access denied back to user
        return 'error'

    return wrapped

def restricted2(func):
    """Add re-stricter for admin only access."""
    @wraps(func)
    def wrapped(bot, update, *args, **kwargs):
        user_id = update.effective_user.id  # get user id
        if user_id in admins:  # if  admin id
            return func(bot, update, *args, **kwargs)  # run function
        update.message.reply_text(
            "Access denied for {}.Ask [Jo](tg://user?id={}) for access.".
            format(user_id, admins[0]),
            parse_mode=ParseMode.MARKDOWN
        )  # else echo access denied back to user
        return 'error'

    return wrapped

def time():
    """Return time in formated string."""
    return str(strftime('%d/%m/%Y %H:%M:%S'))

@restricted2
def spam(bot, update, args):
    """Repetitive messages for debug."""
    if int(args[0]) == 0:  # if interval = 0
        jbq.run_once(
            sendMessage, 0, context=[int(args[1]),
                                     args[2]])  # initiate job to reply
    else:  # for reppetive jobs
        jbq.run_repeating(
            sendMessage,
            interval=int(args[0]),
            first=0,
            context=[int(args[1]), args[2]])  # initiate job to repeat

@restricted2
def halt(bot, update):
    """Turn off glasses."""
    update.message.reply_text(
        'Halting at {}'
        .format(time()))  # echo that command was received
    os.system('sudo halt')  # send shutdown command

@restricted2
def reboot(bot, update):
    """Reboot glasses."""
    update.message.reply_text(
        'Rebooting at {}'
        .format(time()))  # echo that command was received
    os.system('sudo reboot')  # send reboot command

@restricted2
def allowallids(bot, update):
    """Toggle restriction level."""
    global allowAll  # pull allowAll in so function can edit

    if allowAll:  # toggle
        allowAll = False
        update.message.reply_text('allowing restricted ids.')
    else:
        allowAll = True
        update.message.reply_text('allowing all ids.')

@restricted2
def exit(bot, update, args):
    """Exit the program cleanly."""
    if len(args) >= 1:
        f = open('run.txt', 'w+')  # open file
        f.write('no')
        f.close()  # close file
    runningstateset(2)  # set sate to exit
    update.message.reply_text('Exiting at {}'
                              .format(time()))  # echo exiting back to user

@restricted2
def buttons(bot, update):
    """Toggle if the buttons are enabled."""
    buttonstoggle()
    update.message.reply_text('Toggled buttons.')  # echo toggled back to user

@restricted2
def addwifi(bot, update, args):
    """Add WiFi network."""
    ssid = args[0]
    psk = args[1]
    f = open('/etc/wpa_supplicant/wpa_supplicant.conf', 'a')  # open file
    f.write('\nnetwork={\n        ssid="')  # format and store network
    f.write(ssid)
    f.write('"\n        psk="')
    f.write(psk)
    f.write('"\n}\n')
    f.close()  # close file
    update.message.reply_text(
        'added {} to wifi'.format(ssid))  # echo added WiFi back to user

@restricted2
def scalefactor(bot, update, args):
    """Set scale factor."""
    scaleFactorset(float(args[0]))
    update.message.reply_text(
        'scale factor set to {}'.format(float(args[0])))  # echo scale factor

@restricted1
def image(bot, update):
    """Send most recent image from camera."""
    bot.send_photo(
        chat_id=update.message.chat_id, photo=open('image1.jpg',
                                                   'rb'))  # send image

@restricted1
def start(bot, update):
    """Start the glasses cleanly."""
    f = open('users.txt', 'a')  # currently debugging by logging new users
    f.write('{}\n\r'.format(update.message.from_user))
    f.close()
    runningstateset(1)  # set state to running
    update.message.reply_text('started')  # echo started back to user

@restricted1
def stop(bot, update):
    """Stop/pause glasses."""
    runningstateset(0)  # set running state to stopped
    update.message.reply_text('stopped')  # echo stopped back to user

@restricted1
def mode(bot, update, args):
    """Manually change the mode."""
    modeset(int(args[0]))  # set mode
    update.message.reply_text('mode set to {}'.format(
        args[0]))  # echo mode back to user

@restricted1
def colourset(bot, update, args):
    """Set the colour of the lenses."""
    update.message.reply_text(colorSplit(
        args[0]))  # colour information to handler

@restricted1
def autoback(bot, update):
    """Calculate the background tint in manual mode."""
    usrin = getiso()  # get ambient light level
    usrin = 'back@{},{},{}'.format(
        int(usrin), int(usrin),
        int(usrin))  # format string to be passed to handler
    update.message.reply_text(colorSplit(usrin))  # string to handler

@restricted1
def tint(bot, update, args):
    """Set background tint percentage."""
    usrin = 100 - int(args[0])  # invert percentage
    usrin = 'back@{},{},{}'.format(
        int(usrin * 2.56), int(usrin * 2.56),
        int(usrin * 2.56))  # format string to be passed to handler
    update.message.reply_text(colorSplit(usrin))  # string to handler

@restricted1
def debug(bot, update):
    """Toggle command line debug."""
    debugset()  # toggle command line debug
    update.message.reply_text(
        'debug toggled')  # echo that the debug has been toggled back to user

def uprecords(bot, update):
    """Run the uprecords command and echo results."""
    p = subprocess.Popen(
        ['uprecords', '-a'], stdout=subprocess.PIPE, stderr=subprocess.PIPE
    )  # open subprocess in thread and pipe back results
    out = p.communicate()  # collect results
    update.message.reply_text(out[0])  # echo results

def temp(bot, update):
    """Get cpu temperature."""
    temp = int(open('/sys/class/thermal/thermal_zone0/temp').read()) / 1000.0
    update.message.reply_text('CPU temperature is:{}'.format(temp))

def joke(bot, update):
    """Send a joke."""
    update.message.reply_text(choice(jokelist))  # pick random joke and send

def meme(bot, update):
    """Send a meme."""
    memeid = randint(1, 17)  # pick random image
    bot.send_photo(
        chat_id=update.message.chat_id,
        photo=open('memes/{}.jpg'.format(memeid), 'rb'))  # send image

def help(bot, update):
    """Display help menu."""
    update.message.reply_text(
        'help im stuck in a box \n\r' +
        '/pickcolour - pick from list of tints\n\r' +
        '/pickmode- pick from list of modes\n\r' +
        '/tint percentage\n\r' + '/colourset fore-back@0-255,0-255,0-255\n\r' +
        '/start starts shades\n\r' + '/stop stop shades\n\r' +
        'for more info check the [site](git.djh1997.uk)',
        parse_mode=ParseMode.MARKDOWN)

def up(bot, update):
    """Check if glasses are online."""
    update.message.reply_text('shades {} is online.'.format(test_box))

def echo(bot, update):
    """Catch all for unrecognised commands."""
    update.message.reply_text('command {} not recognised.'.format(
        update.message.text))  # echo that the command was unrecognised
    f = open('log.txt', 'a')  # log the user id and message
    f.write('{} : '.format(update.message.text))
    f.write('{}\n\r'.format(update.message.from_user))
    f.close()

def pickcolour(bot, update):
    """Inline keyboard to pick a preset colour."""
    keyboard = [[
        InlineKeyboardButton("50", callback_data=50),
        InlineKeyboardButton("80", callback_data=80),
        InlineKeyboardButton("90", callback_data=90),
        InlineKeyboardButton("100", callback_data=100)
    ], [
        InlineKeyboardButton("red", callback_data=101),
        InlineKeyboardButton("green", callback_data=102),
        InlineKeyboardButton("blue", callback_data=103),
        InlineKeyboardButton("gold", callback_data=104)
    ]]  # setup layout

    reply_markup = InlineKeyboardMarkup(keyboard)  # create keyboard

    update.message.reply_text(
        'Please choose:', reply_markup=reply_markup)  # send keyboard

def pickmode(bot, update):
    """Inline keyboard to pick mode."""
    keyboard = [[
        InlineKeyboardButton("manual", callback_data=0),
        InlineKeyboardButton("tint", callback_data=1),
        InlineKeyboardButton("point", callback_data=2),
        InlineKeyboardButton("full auto", callback_data=3),
        InlineKeyboardButton("negative", callback_data=4)
    ]]  # setup layout

    reply_markup = InlineKeyboardMarkup(keyboard)  # create keyboard

    update.message.reply_text(
        'Please choose:', reply_markup=reply_markup)  # send keyboard

def button(bot, update):
    """Create handler for inline keyboard."""
    query = update.callback_query
    tint = int(query.data)  # convert button id to int
    if tint <= 4:  # if mode button
        modeset(tint)  # set mode
        bot.edit_message_text(
            text="mode set to {}".format(tint),
            chat_id=query.message.chat_id,
            message_id=query.message.message_id)  # echo new mode
    else:  # if tint setting
        if tint <= 100:  # if standard tint
            tint = int(tint * 2.55)  # format tint
            tint = '{},{},{}'.format(tint, tint, tint)  # format tint
        elif tint == 101:  # if colour tint
            tint = '255, 200, 200'  # red
        elif tint == 102:
            tint = '200, 255, 200'  # green
        elif tint == 103:
            tint = '200, 200, 255'  # blue
        elif tint == 104:
            tint = '255, 223, 0'  # gold
        bot.edit_message_text(
            text="Selected option: {}".format(
                colorSplit('back@{}'.format(tint))),
            chat_id=query.message.chat_id,
            message_id=query.message.message_id)  # set tint and echo result

def colorSplit(usrin):
    """Colour handler."""
    error = False
    usrin = usrin.split('@')  # split colour and location
    tint = usrin[1].split(',')  # split colours
    reply = ''
    for i in range(len(tint)):  # iterate over rgb values
        tint[i] = int(tint[i])  # convert to int
        if tint[i] not in range(0, 257):  # check value is in valid range
            reply = 'rgb out of range'  # warn user of error
            error = True  # trigger error
    if error is False:  # if all values in spec
        if usrin[0] == 'back':  # set background tint
            tintBackset(tint)  # data to handler
            reply = tint  # echo back the rgb values
        elif usrin[0] == 'fore':  # set foreground tint
            tintShadeset(tint)  # data to handler
            reply = tint  # echo back the rgb values
        else:  # if not fore or back warn user and show formatting
            reply = 'valueError format like this fore-back@0-255,0-255,0-255'
    return reply

def sendMessage(bot, job):
    """Send message handler for job_queue."""
    bot.send_message(chat_id=job.context[0], text=job.context[1])

def telegramMain():
    """Telegram main function."""
    global updater

    # Get the dispatcher to register handlers
    dp = updater.dispatcher

    # on different commands - answer in Telegram
    # all
    dp.add_handler(CommandHandler("help", help))
    dp.add_handler(CommandHandler("uprecords", uprecords))
    dp.add_handler(CommandHandler("up", up))
    dp.add_handler(CommandHandler("temp", temp))
    dp.add_handler(CommandHandler('joke', joke))
    dp.add_handler(CommandHandler('meme', meme))

    # togglable
    dp.add_handler(CommandHandler("start", start))
    dp.add_handler(CommandHandler("stop", stop))
    dp.add_handler(CommandHandler("mode", mode, pass_args=True))
    dp.add_handler(CommandHandler("autoback", autoback))
    dp.add_handler(CommandHandler("tint", tint, pass_args=True))
    dp.add_handler(CommandHandler("colourset", colourset, pass_args=True))
    dp.add_handler(CommandHandler('pickcolour', pickcolour))
    dp.add_handler(CommandHandler('pickmode', pickmode))
    dp.add_handler(CommandHandler('image', image))
    dp.add_handler(CommandHandler('debug', debug))

    # admins only
    dp.add_handler(CommandHandler("exit", exit, pass_args=True))
    dp.add_handler(CommandHandler('spam', spam, pass_args=True))
    dp.add_handler(CommandHandler('allowallids', allowallids))
    dp.add_handler(CommandHandler("halt", halt))
    dp.add_handler(CommandHandler("reboot", reboot))
    dp.add_handler(CommandHandler("buttons", buttons))
    dp.add_handler(CommandHandler("addwifi", addwifi, pass_args=True))
    dp.add_handler(CommandHandler("scalefactor", scalefactor, pass_args=True))

    # keyboard handler
    dp.add_handler(CallbackQueryHandler(button))

    # on noncommand i.e message - echo the message on Telegram
    dp.add_handler(MessageHandler(Filters.text, echo))
    dp.add_handler(MessageHandler(Filters.command, echo))

    # Start the Bot
    updater.start_polling()

    # Run the bot until you press Ctrl-C or the process receives SIGINT,
    # SIGTERM or SIGABRT. This should be used most of the time, since
    # start_polling() is non-blocking and will stop the bot gracefully.
    jbq.run_once(sendMessage, 0, context=[
                 admins[0], 'Shades booting at {}'.format(time())])
    while runningstateget() != 2:
        if runningstateget() != 1:
            runningstateset(1)
            sandd()
    # updater.idle()
    updater.stop()

telegramMain()
```

### shades.py

```python
"""Pi0to chromic control file."""
import os
from time import sleep, time

import Adafruit_GPIO.SPI as SPI
import ST7735 as TFT
from gpiozero import Button
from picamera import PiCamera  # camera
from PIL import Image
from skimage.feature import blob_doh  # blob detection
from skimage.io import imread  # convert jpg to np array

"""screen variables"""
WIDTH = 128
HEIGHT = 160
SPEED_HZ = 125000000

scaleFactor = .25

"""Raspberry Pi configuration."""
DC = 24
RST = 25
SPI_PORT = 0
SPI_DEVICE = 0

"""program variables"""
processpoint = [['clear', 'display'], ['autoback', 'clear', 'display'], [
    'take', 'convert', 'blob find', 'blob to point', 'clear', 'point maths',
    'display'
], [
    'autoback', 'take', 'convert', 'blob find', 'blob to point', 'clear',
    'point maths', 'display'
], ['take', 'display']]
averageFps = []
running = 0
tintShade = [32, 32, 32]
tintBack = [256, 256, 256]
tintbuttonvar = 255
mode = 0
debug = 0
disp = 0
draw = 0
camera = 0
buttons = 1
new = True

"""button connection"""
buttonTint = Button(2)
buttonMode = Button(3)
buttonDebug = Button(4, hold_time=5)
"""buttonReset = Button(14, hold_time=2)
buttonexit = Button(15, hold_time=5)"""

def initlcd():
    """Initilize the lcd's."""
    global disp, draw
    print 'initializing LCD'
    disp = TFT.ST7735(
        DC,
        rst=RST,
        spi=SPI.SpiDev(SPI_PORT, SPI_DEVICE,
                       max_speed_hz=SPEED_HZ))  # setup SPI port
    disp.begin()  # start screen class
    disp.display(
        Image.open('pi0toChroma.jpg').rotate(270).transpose(
            Image.FLIP_TOP_BOTTOM).resize((WIDTH,
                                           HEIGHT)))  # draw splash screen
    draw = disp.draw()  # put splash screen on LCD's
    print 'LCD initialized'

def deinitlcd():
    """Deinitilise the lcd."""
    global disp
    disp.display(Image.open('close.jpg').rotate(90).resize(
        (WIDTH, HEIGHT)))  # display close screen
    sleep(.5)
    disp.clear((256, 256, 256))  # set LCD to clear
    disp.display()
    print 'LCD cleared'

def initcamera():
    """Initilize the camera."""
    global camera
    print 'initializing camera'
    camera = PiCamera()  # open camera
    camera.color_effects = (128, 128)  # set camera to grey scale
    camera.resolution = (int(160 * scaleFactor),
                         int(128 * scaleFactor))  # set resolution to screens
    camera.rotation = 270  # correct orinetation
    camera.vflip = True
    if debug == 1:  # if debug was called before camera initialization was run
        camera.start_preview()  # start camera preview
    sleep(3)  # wait for camera to stabilise
    print 'camera initialized'

def deinitcamera():
    """Disconnect camera so the next instance of the program can access."""
    global camera
    camera.close()
    print 'camera closed'

def scaleFactorset(newsf):
    """Change the scake factor."""
    global scaleFactor
    scaleFactor = newsf
    camera.resolution = (int(160 * scaleFactor),
                         int(128 * scaleFactor))  # set resolution to screens

def debugset():
    """Toggle debug."""
    global debug
    if camera != 0:  # check if camera initialization has been run
        if debug == 0:  # toggle preview
            camera.start_preview()
        else:
            camera.stop_preview()
    else:
        # if camera initialization hasn't  been run print warning
        print 'camera not defined yet'

    debug ^= 1  # toggle debug
    if debug == 1:  # print new debug state
        print 'debug on'
    else:
        print 'debug off'

def runningstateset(state):
    """Set running state."""
    global running
    # try:  # try assuming state is a button
    #     if state.pin.number == buttonReset.pin.number and state.is_held:
    #         state = 1  # set state to running
    #     elif state.pin.number == buttonReset.pin.number:
    #         state = 0  # set state to stopped
    #     elif state.pin.number == buttonexit.pin.number and state.is_held:
    #         state = 2  # set state to exit
    # except AttributeError:  # catch not button error
    #     print 'not button'  # print warning
    print 'state ' + str(state)  # print new state
    running = state  # set state

def tintShadeset(tint):
    """Set Shade tint."""
    global tintShade
    tintShade = tint  # set tint level for active shade points

def autoshadeset(tintdifference):
    """Set shade point tint unsing background and difference."""
    global tintShade
    for i in range(len(tintShade)):
        tintShade[
            i] = tintBack[i] - tintdifference  # set tint difference points

def tintBackset(tint):
    """Set background tint."""
    global tintBack, new
    tintBack = tint  # set tint level for background
    new = True

def tintButton(buttonTint):
    """Set the background tint based on button presses."""
    global tintBack, tintbuttonvar
    if buttonTint.is_held or tintbuttonvar < 64:  # if button is held reset
        tintbuttonvar = 256  # set tint to clear
    elif tintbuttonvar >= 64:  # increment tint if not at limit
        tintbuttonvar -= 64
    tintBackset([tintbuttonvar, tintbuttonvar, tintbuttonvar])  # set tint
    print tintBack

def modeset(modevar):
    """0 manual 1 tint 2 point 3 auto 4 negative."""
    global mode, averageFps, new
    try:  # try assuming modevar is a button
        if modevar.pin.number == 3 and modevar.is_held:
            modevar = 0  # reset mode to manual
        elif modevar.pin.number == 3:
            if mode >= 4:  # if at limit the reset to manual
                modevar = 0
            else:  # else increment
                modevar = mode + 1
    except AttributeError:  # catch not button error
        print 'not button'  # print warning
    if modevar == 4:
        camera.hflip = True
        camera.image_effect = 'negative'
    else:
        camera.hflip = False
        camera.image_effect = 'none'
    mode = modevar  # set mode
    averageFps = []  # reset average fps array
    tintBackset([256, 256, 256])
    tintShadeset([32, 32, 32])
    new = True
    print 'mode ' + str(mode)  # display new mode

def runningstateget():
    """Return current state."""
    global running
    return running

def getiso():
    """Get iso level of sensor.."""
    global camera
    maxtint = 4
    iso = float(camera.analog_gain)  # get current ambient brightness 0..8
    iso = (iso * maxtint)  # adjust buy max tint level
    iso = (256 - (maxtint * 8)) + iso  # clear - max tint + ISO tint
    return int(iso)

def halt():
    """Halt the system."""
    os.system('sudo halt')  # send halt command to terminal

def initbuttons():
    """Initilize buttons.

    Wait for all button to be released
    Then asign to correct function.
    """
    print 'initializing butoons'
    buttonTint.wait_for_release(
    )  # wait incase any of the buttons are locked high
    buttonMode.wait_for_release()
    buttonDebug.wait_for_release()
    # buttonReset.wait_for_release()
    # buttonexit.wait_for_release()
    buttonTint.when_pressed = tintButton  # set button state to function
    buttonTint.when_held = tintButton
    buttonMode.when_pressed = modeset
    buttonMode.when_held = modeset
    buttonDebug.when_pressed = debugset
    # buttonDebug.when_held = halt
    # buttonReset.when_pressed = runningstateset
    # buttonReset.when_held = runningstateset
    # buttonexit.when_held = runningstateset
    print 'buttons initialized'

def deinitbuttons():
    """Deinitilize buttons.

    Release button from function.
    """
    print 'Deinitializing buttons'
    buttonTint.when_pressed = None  # set button state to function
    buttonTint.when_held = None
    buttonMode.when_pressed = None
    buttonMode.when_held = None
    buttonDebug.when_pressed = None
    # buttonDebug.when_held = None
    # buttonReset.when_pressed = None
    # buttonReset.when_held = None
    # buttonexit.when_held = None
    print 'Deinitilized buttons'

def buttonstoggle():
    """Toggle buttons."""
    global buttons
    buttons ^= 1
    if buttons == 0:
        deinitbuttons()
    else:
        initbuttons()

def sandd():
    """Pi0t0 chromic main function.

    This handles the main running of the shades.
    This is done by having nested while loops to control different states.
    Then there is if statments to control weather the system reactes to the
    camera or not, and how to update the lenses
    """
    global averageFps, new
    initlcd()  # initialize peripherals
    initbuttons()
    initcamera()
    while running != 2:  # exit state
        while running == 1 and new:  # running state and new
            timer = []  # reset internal variables
            points = []
            modeinternal = mode

            if (modeinternal == 1) or (
                    modeinternal == 3):  # if mode with auto background tint
                timer.append(time())  # add timer point
                ti = getiso()  # get light level
                tintBackset([ti, ti, ti])  # calculate background tint
                if modeinternal == 3:
                    autoshadeset(ti)

            if modeinternal >= 2:  # if camera mode
                timer.append(time())  # add timer point

                camera.capture(
                    'image1.jpg', use_video_port=True,
                    thumbnail=None)  # capture image

            if modeinternal == 4:  # if negative mode
                timer.append(time())  # add timer point
                disp.display(Image.open('image1.jpg').rotate(90).resize(
                    (WIDTH, HEIGHT)))  # display image

            if (modeinternal == 2) or (modeinternal == 3):  # if point shading
                timer.append(time())  # add timer point
                img1 = imread('image1.jpg', as_grey=True)

                timer.append(time())  # add timer point
                blobs_doh = blob_doh(
                    img1, max_sigma=15, threshold=.0075)  # find blobs

                timer.append(time())  # add timer point

                for i in range(len(blobs_doh)):  # calculate points from blobs
                    points.append([
                        blobs_doh[i][0] / scaleFactor,
                        blobs_doh[i][1] / scaleFactor,
                        (blobs_doh[i][1] / 3) / scaleFactor, tintShade
                    ])  # x,y,r,tint

            if modeinternal <= 3:  # not negative mode
                timer.append(time())  # add timer point

                disp.clear((tintBack[2], tintBack[1],
                            tintBack[0]))  # set background tint

            if (modeinternal == 2) or (modeinternal == 3):  # if point shading
                timer.append(time())  # add timer point
                for i in range(0,
                               len(points)):  # convert x,y,r to bounding box
                    x1 = int(points[i][0] - points[i][2])
                    x2 = int(points[i][0] + points[i][2])
                    y1 = int(points[i][1] - points[i][2])
                    y2 = int(points[i][1] + points[i][2])
                    draw.ellipse(
                        (x1, y1, x2, y2),
                        fill=(points[i][3][2], points[i][3][1],
                              points[i][3][0]))  # draw

            if modeinternal <= 3:  # not negative mode
                timer.append(time())  # add timer point
                disp.display()  # put the drawing on the the LCD's

            timer.append(time())  # add timer point

            if modeinternal == 0:  # if in mode 0 then toggle new
                new = False
            else:
                new = True

            if debug == 1:  # if debug is on the print timings

                print 'number of points: {}\n'.format(len(points))
                print 'points:{}\n'.format(points)
                print 'background tint: {}\n'.format(tintBack)
                print 'foreground tint: {}\n'.format(tintShade)
                for t in range(0,
                               len(timer) -
                               1):  # iterate over timing list to get timings
                    print 'function {} : time {}\n'.format(
                        processpoint[modeinternal][t],
                        timer[t + 1] - timer[t])  # print function and time

                totaltime = timer[len(timer)
                                  - 1] - timer[0]  # calculate total time
                averageFps.append(1 / totaltime)  # calculate fps and append
                if len(averageFps) >= 11:  # buffer has min number of values
                    if len(averageFps) >= 61:  # buffer full then remove oldest
                        averageFps.pop(0)
                    print 'average fps = {: 4.2f}\n'.format(
                        sum(averageFps) / len(averageFps))  # print average fps
                print 'total = {: 4.2f}  fps = {: 4.2f}\n'.format(
                    totaltime, averageFps[len(averageFps)
                                          - 1])  # print total time and fps

        sleep(1)

    deinitlcd()  # close peripherals
    deinitcamera()
```
[^1]:[https://youtu.be/E5d7ynJXiZc?t=4m32s](https://youtu.be/E5d7ynJXiZc?t=4m32s)

[^2]:[https://www.ibuypower.com/Signature/Snowblind](https://www.ibuypower.com/Signature/Snowblind)
[^3]:[http://www.e-tintproducts.com](http://www.e-tintproducts.com)

[^4]:[http://www.e-tintproducts.com/technology/](http://www.e-tintproducts.com/technology/)

[^5]:[http://www.e-tintproducts.com/ctrl-eyewear/](http://www.e-tintproducts.com/ctrl-eyewear/)

[^6]:[http://www.ganttproject.biz/](http://www.ganttproject.biz/)

[^7]:[https://picamera.readthedocs.io/](https://picamera.readthedocs.io/)

[^8]:[https://github.com/cskau/Python_ST7735](https://github.com/cskau/Python_ST7735)

[^9]:[https://dle.plymouth.ac.uk/mod/resource/view.php?id=328795#page=5](https://dle.plymouth.ac.uk/mod/resource/view.php?id=328795#page=5)

[^10]:[http://scikit-image.org/](http://scikit-image.org/)

[^11]:[https://python-telegram-bot.org/](https://python-telegram-bot.org/)

[^12]:[https://github.com/python-telegram-bot/python-telegram-bot/wiki/Code-snippets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](https://github.com/python-telegram-bot/python-telegram-bot/wiki/Code-snippets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)

[^13]:[https://ec.europa.eu/research/participants/data/ref/h2020/wp/2014_2015/annexes/h2020-wp1415-annex-g-trl_en.pdf](https://ec.europa.eu/research/participants/data/ref/h2020/wp/2014_2015/annexes/h2020-wp1415-annex-g-trl_en.pdf)

[^14]:[http://www.earto.eu/fileadmin/content/03_Publications/The_TRL_Scale_as_a_R_I_Policy_Tool_-_EARTO_Recommendations_-\_Final.pdf#page=7](http://www.earto.eu/fileadmin/content/03_Publications/The_TRL_Scale_as_a_R_I_Policy_Tool_-_EARTO_Recommendations_-_Final.pdf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)

[^15]:[https://www.ttp.com/case-studies/electronic_lenses](https://www.ttp.com/case-studies/electronic_lenses)

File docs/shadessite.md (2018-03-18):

# **Final Year Project**

pi0toChroma logo

# Stage Criteria

This is the criteria I would like to meet, to feel as though I have created a successful project.

| Stage | Name | Description |
| ----- | --- | --- |
| 1 | Smart shades | Make a set of smart sun classes |
| 2 | Auto smart shades | Add LDR to control the opacity |
| 3 | Auto smart point shades | Add camera to make dark point over bright points |
| 4 | Controllable smart shades | Add options to swap between modes |
| 5 | Driving/safety improvements | Auto react headlights etc. |

## Inspiration

[indie-go-go](https://www.indiegogo.com/projects/ctrl-one-the-smartest-lcd-tint-changing-glasses-smart#/)

[ctrl-eyewear](http://www.ctrl-eyewear.com/)

[pc case](https://www.youtube.com/watch?v=E5d7ynJXiZc)

## Plan

The product's above, along with Paul's lectures last year inspired my idea.

The plan is to use two LCD's with the backlight removed, to create dimmable panels in front of the users eyes. Then eventually I will add a camera to make point control which will block bright spots such as projectors and the sun, and dim them to reduce squinting.

# Final mock-up

final mock-up design image

So, once I have removed the backlight from the LCD's I can mount them in a frame. I can then begin to control the contrast/pixel density to make them dim. I will then add a LDR to automate the brightness selection, this will remove the manual adjust however I will leave the buttons to set the levels. Next I will add a camera to the system so that the system can also detect bright points hence make a matching point darker on the lens. I will then use the buttons to make it so that you can swap between the modes. The final additional feature I would like to add is some intelligence on the camera side to ignore certain circumstances such as car tail/headlights

# Report

I got the LCD hooked up and displayed some random spots of different opacity on the screen

[random point video](log/IMG_1188.TRIM.MOV)

I tried to install opencv to do the image processing built the install failed and after I spoke to my supervisor he confirmed my suspicion that opencv was too over powered for my project.

So I did some more research around low power blob detection in python and found Skimage which has a function for Determinant of Hessian(doh) blob detection which should be quick enough the only issue I then had was getting the image from the camera into the right format since the doh blob need a numpy array as luck would have it skimage has a built in converter.

With this working a passed it an image from the camera and save the image with a circle around the blob.

blob circle

I then connected the LCD and got blob detection working with that.

blob lcd

Then I started to convert the shades.py (the file that controls the lcd and camera) and telegrambot.py (the script that enables remote control via a chat client bot) this involved more work than I had initially expected since passing variable around wasn't as easy as I had hoped

I decided to use telegram to add remote control so that you could adjust the colour of the tint [remote control](https://t.me/smartsheadsfypbot)

| command | param | Description |
| --- | --- | --- |
| help | na | show the help menu |
| pickcolour  | pick from list of tints | preset tints/colours |
| pickmode | pick manual,tint,points or full auto | change current mode |
| joke | na | tells a joke |
| meme | na | shows a meme |
| tint | percentage | sets the tint of the lenses |
| image | na | shows you the current image |
| up | na | see if the bot is up |
| temp | na | see the CPU temperature |
| start | na | starts shades |
| stop | na | stop shades |
| exit | na | exit shades |
| reboot | na | reboot shades |
| halt | na | shutdown shades |
| uprecords | na | see up time |
| debug | na | toggles debug |
| colourset | fore/back@0/255,0/255,0/255 | sets the colour of the lenses |
| allowallids | na | toggles if admin id is needed |

After I had all of the system working I bought a 5 button capacitive touch sensor and started adding that into the code so that I would be able to control the glasses with out having to have it connected to the internet

| button | pressed | held |
| --- | --- | --- |
| 1 | scroll tints | reset tint to clear |
| 2 | scroll modes | reset to manual |
| 3 | debug | turn off |
| 4 | stop | start |
| 5 | na | exit |

# capacitive touch control

[mode change](log/capmode.MOV)
[tint change](log/tint.MOV)
[debug toggle](log/debug.MOV)

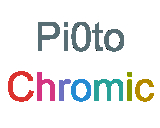
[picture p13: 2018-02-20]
design/code/pi0toChroma.jpg

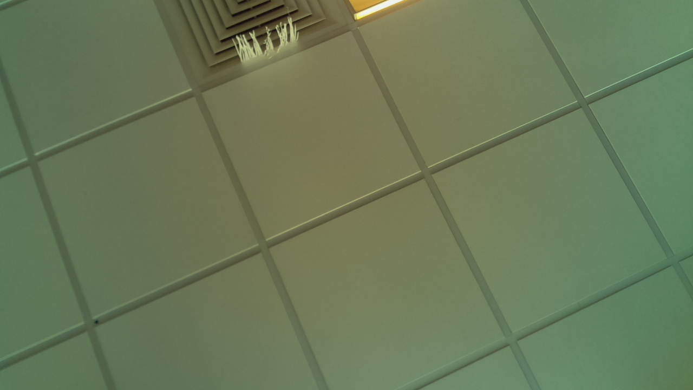
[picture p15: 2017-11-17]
design/vision/camera/1st eduroam.jpg

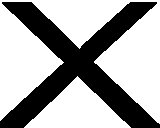
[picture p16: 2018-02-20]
design/code/close.jpg

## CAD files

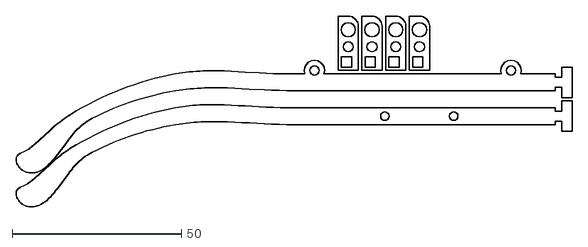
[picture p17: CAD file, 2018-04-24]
design/frame/armstocut.dxf
164.0 x 56.2

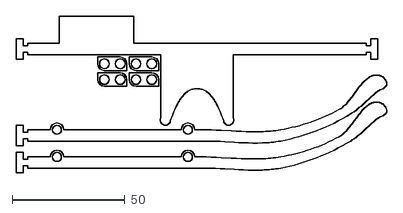
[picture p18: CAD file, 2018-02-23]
design/frame/frametocut.dxf
164.0 x 69.2

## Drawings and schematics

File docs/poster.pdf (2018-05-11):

# Frame Development Cycle

Command | Parameters | Description

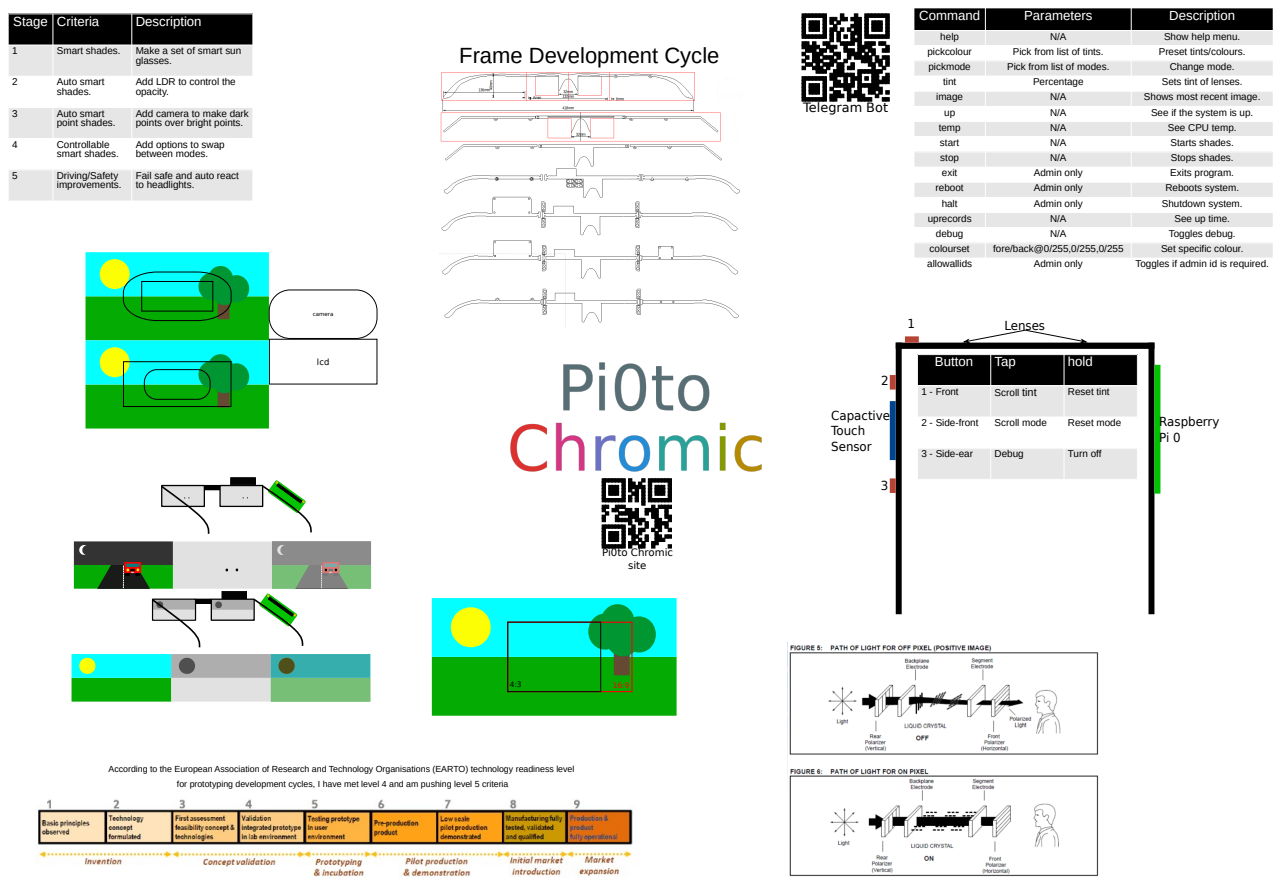
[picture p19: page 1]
pickcolour; Pick from list of tints.; Preset tints/colours.; pickmode; Pick from list of modes.; Change mode.; tint; Percentage; Sets tint of lenses.; image; Shows most recent image.; See if the system is up.; Pi0to Chromic site; Telegram Bot; Smart shades.; Make a set of smart sun; glasses.; Auto smart; shades.; point shades.; camera; lcd; Button; Tap; hold; 1 - Front; Scroll tint; Reset tint; 2 - Side-front; Scroll mode; Reset mode; 3 - Side-ear; Debug; Turn off; Raspberry Pi 0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

Stage | Criteria | Description

help | N/A | Show help menu.

Add LDR to control the
opacity.

Add camera to make dark
points over bright points.

temp | N/A | See CPU temp.
start | N/A | Starts shades.
stop | N/A | Stops shades.
exit | Admin only | Exits program.
reboot | Admin only | Reboots system.
halt | Admin only | Shutdown system.
uprecords | N/A | See up time.
debug | N/A | Toggles debug.
colourset | fore/back@0/255,0/255,0/255 | Set specific colour.
allowallids | Admin only | Toggles if admin id is required.

4 | Controllable smart shades. | Add options to swap between modes.

5 | Driving/Safety improvements. | Fail safe and auto react to headlights.

According to the European Association of Research and Technology Organisations (EARTO) technology readiness level

for prototyping development cycles, I have met level 4 and am pushing level 5 criteria

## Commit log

2017-10-02 add camera
2017-10-02 add last years code for camera work
2017-10-26 add vhdl vs arm
2017-10-26 investigate camera lcd and compute options
2017-10-28 add possiable camera libarys for mbed
2017-10-28 update stage objectives
2017-10-28 update stage opjectives
2017-11-01 spelling and adding raspberry pi
2017-11-17 add to log and correct adc to ADC
2017-11-18 add frame
2017-11-19 add pi zero holes
2017-11-19 place pi moing on frame
2017-11-19 correct hole size
2017-11-28 add hinge
2018-02-02 improve task list and add lcd pin out table and wifi config
2018-02-05 add lcd driver
2018-02-07 update log with open cv switch
2018-02-13 switch lcd drivers
2018-02-15 switch to skimage
2018-02-15 switch to personal fork
2018-02-15 get camera working
2018-02-16 update driver
2018-02-16 add names to timers
2018-02-17 fix timing for just tint mode
    [shades.py]
2018-02-19 add frame to cut
    [frametocut.dxf]
2018-02-19 remove dim line and wire slot
2018-02-20 update uni lazer cutter file
    [frametocut.dxf]
2018-02-20 adjust fram to move lenses up
    [frametocut.dxf]
2018-02-22 add wiring photos
2018-02-22 set spi speed to max
2018-02-22 Removed submodule design/vision/lcd/driver
2018-02-23 update farm to have hinge
    [frametocut.dxf]
2018-02-23 add pin out for pi header
2018-02-27 make new arms to increase clerance and mounting for the pi 0
2018-02-27 correct orientation for the camera
    [shades.py]
2018-03-06 fix debug to early and reset average on mode change
    [shades.py]
2018-03-09 start adding buttons
2018-03-12 formating and add capactive buttons to report
2018-03-13 add de/init prints
2018-03-13 update button on index and fix error
    [shades.py]
2018-03-14 add more button functionality
2018-03-14 add sutck high on boot protection and fix mode 4 error
    [shades.py]
2018-03-14 correct splash screen and add wait for camera to stabilize
    [shades.py]
2018-03-17 tidy prints and disable halt to stop accidental shutdowns
2018-03-18 add autoshade
    add code to make it so that there is configerable differenc between fore and back ground
2018-03-18 add better iding and error handling
    [telegrambot.py]
2018-04-09 correct indenting and switch to real config file
    [telegrambot.py]
2018-04-12 update privillage error and help text
    [telegrambot.py]
2018-04-17 add colour to the buttons
2018-04-17 add capacitive touch board mounting point
2018-04-17 remove pcb back plates
2018-04-20 export for cutting
    [armstocut.dxf]
2018-04-20 add print for debug toggle
2018-04-20 improve access error reply
    [telegrambot.py]
2018-04-20 add link to both access error replys and add link to help
    [telegrambot.py]
2018-04-22 add time log to commands to find reboot time of 2-3 minuets
    [telegrambot.py]
2018-04-22 add points to debug print
2018-04-23 correct onlt update lcd on new valuse in manual mode
    [shades.py]
2018-04-24 cut new arms
    [armstocut.dxf]
2018-04-24 crop out extra lens
2018-04-30 make buttons more dynamic
2018-05-01 start work on making buttons toglable
2018-05-02 finish togglable buttons
2018-05-03 reset tints on mode change
    [shades.py]
2018-05-09 add vision and buttons to poster
2018-05-09 add buttons to poster and update log
2018-05-10 add buttons to poster
2018-05-10 improve button diagram
2018-05-10 add buttons and wakatime to site
2018-05-10 add links to appendix and button explination
2018-05-11 format compute and add camera
2018-05-12 add electric lens reference
2018-05-13 comment out unused buttons
2018-05-20 Add flowchart
2018-05-20 Added flowchart.svg
2018-05-20 updated flowchart.svg
2018-05-20 add flowcart and correct gantt
2018-05-20 add flowchart to log
2018-05-20 embed flowchart
